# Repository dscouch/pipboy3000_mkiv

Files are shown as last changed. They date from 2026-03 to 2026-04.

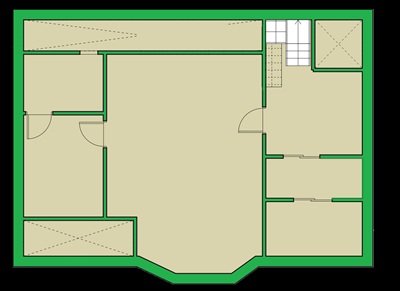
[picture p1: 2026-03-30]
images/map3.jpg

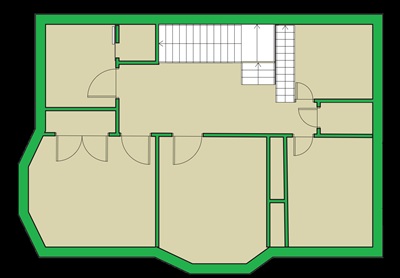
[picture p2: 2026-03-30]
images/map2.jpg

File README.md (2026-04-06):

# Vault 27 Engineering Logs: Easter 2026 Pip-Boy Project

## Overview
A multiplayer Pip-Boy 3000 (Mark IV) replica built for an immersive Easter puzzle experience. The system relies on asymmetric gameplay (similar to *Keep Talking and Nobody Explodes*), forcing two Vault Dwellers (793 and 612) to cooperate, swap roles, and manage "Radiation Sickness" to decode a final meta-puzzle.

## Hardware Architecture
* **Main Display:** 5" ESP32-S3 Capacitive Touch Display - VIEWE Model：UEDX80480050E-WB-A https://viewedisplay.com/product/esp32-5-inch-800x480-rgb-ips-tft-display-touch-screen-arduino-lvgl/
* **Co-processor:** ESP32-C3 Super Mini connected via serial. Dedicated to efficient BLE MAC address scanning for radiation hotspots, and driving a haptic motor and piezo speaker for Geiger counter feedback.
* **RFID/NFC:** PN532 module for localized object scanning. (in I2C mode)
* **Power:** USB plug to a  TP4056 lipo charger feeding into an MT3608 Boost Converter to make a 5v supply. Currently powered by a single 18650, the battery is severly undersized for any longevity. (also the power meter is pretty bad at accurately measuring the voltage.)
* **I/O Expansion:** PCF8575 or MCP23017 I/O expander for managing peripherals like rotary encoders and LEDs.(have not acquired...  on hold)
* **Radiation Sources (x4):** Xiao-ESP32-C3 microcontrollers running `esp32_ble_server`.
* **Note:** the wiring from the rotary encoder is red/black for the push button switch and blue/green/yellow for the encoder portion. (find ports for this ...  and a use!)
* **Also Note:** There is a speaker buried in the front panel that I still haven't decided what to do with. 

## UEDX80480050E Board GPIO Selection
* **UART for Co-processor** Used marked Tx/Rx next to GND on left header set.  Also used by USB/UART but available when not updating
* **PN532** GND=GND, SDA=GPIO19, SCL=GPIO20 on the left and VCC connects to the top of that header
* **5v Power** Tapped the left side of diode D3 that is on VBUS2 of the USB port which enables ability to input 5v from a battery source for regulation into 3V3 VDD

## ID's to track ##
* **Alpha UID:** 04-63-EB-5B-C2-2A-81
* **Beta UID:** 04-21-75-94-D2-2A-81
* **Charlie UID:** 04-FA-F4-94-D2-2A-81
* **Delta UID:** 04-A9-75-5B-C2-2A-81
* **1:**  UID: 04-E5-7B-5B-C2-2A-81
* **2:**  UID: 04-54-55-5B-C2-2A-81
## DWELLER PIP BOY SERIAL NUMS ##
* **Dweller 793:** E793X4
* **Dweller 612:** D612Z5

## UI Design Note ##
Due to the physical design and shape of the pip-boy the screen is more "squarish" with a portion of the 5" esp32 display actually insde the case and not visible.
This means that functionally we only have a 600x480 screen starting at x=200, y=0.  All visible UI components and LVGL widgets should be contained in that area of the screen.

## Software & Infrastructure
* **Framework:** ESPHome integrated with Home Assistant.
* **Codebase Structure:** A highly modular design utilizing YAML anchors and substitutions within a single document. This allows seamless switching of parameters between Dweller 793 and 612 without relying on multiple `!include` files.
* **State Management:** Home Assistant acts as the Overseer, handling cross-device state syncing via `input_number.dweller_${id}_xxx`, game tweaks, and manual triggers (like the Reactor Meltdown) and the mystery cell in the Memory Core Repair menu

## Gameplay Mechanics
* **Radiation Management:** Players scan for specific BLE MAC addresses at 4 hotspots. Staying in a hotspot increases Rads. If Rads exceed 25, the HUD and docs glitch out, forcing players to swap roles (Scanner vs. Manual Reader).
* **Anti-Cheese Systems:** Scans have strict 10-second timeouts. Furthermore, the scanner must actively take radiation damage (Rads > 25) to solve the puzzle, preventing players from simply disabling the radiation source.
* **Progression:** Solving the 4 hotspot puzzles yields encrypted data fragments stored in the INV Tab. The S.P.E.C.I.A.L. stats (STAT Tab) act as the decryption cipher, providing the variables needed for the final logic grid puzzle (DATA Tab).

## Menus
* **STAT** Shows RADs and basic information (can expand this) - STATUS, SPECIAL, and PERKS - SPECIAL contains stats that will change when enough HP is gained and will show the pad to unlock the final encyrpted message.
* **INV** Will be the collection point for the puzzle data and the scanner for the 4 radiation clues (KTANE style)
* **DATA** magic grid where the cells have to add to 30 in every row and colunn and cells values can't be duplicated. Some of the cells are locked and one special cell in the upper left side is actually controlled by the other pip boy.  There is a mystery cell outside the grid that is what controls the upper left cell on the other pip boy.
* **MAP** contains a map (just a static image) of the house with pulsating dots (4) indicating where the radiation source puzzles are located.  In a submenu it also contains the docs for solving the puzzles.  The docs can't be opened (or glitch) when rads>25 to prevent both dwellers from being at the source at the same time.

## Current Development Roadmap

* **Game Logic:** Developing the core logic for the INV, MAP, and RADIO tabs.
* **DATA MENU** finish configuring the puzzle and connect the mystery cell through HomeAssistant
* **MAP MENU** Load screen with mini map of house. figure out how to overlay the beacon locations (figure out locations)(done) - Create menu and doc system where the docs are stored in HA and loaded on the fly as needed (or we can just store it in code if we have enough space)
* **INV MENU** Still thinking about this one. I kind of want to have 4 items displayed and when you NFC scan a beacon it opens one of the puzzles. Maybe the puzzles are on a completely different page and we just use the INV to record which ones they got and provide the encrypted messages?  Anyway, the puzzles need to be of a specific KTANE type but have 4 defined puzzles (images or text) that can be rotated through.  there's an active countdown timer and the beacon has to be rescanned every 10 seconds to reset the countdown and continue or the puzzle blanks out and if you rescan after the countdown runs out you get the next puzzle.
* **DEATH**  In the potential event that one of them "DIES" it will flip to a screen that says something like "Vault Dweller sustained too much damage to continue.  INITIATING CLONING SEQUENCE (with a timeout timer of 99 seconds) at which point the pip-boy reboots.  Attempting to reboot the pip-boy before cloning is complete will just drop them in the same page with a fresh 99 second timer - completion managed by HomeAssistant.  All stats and accomplishments should be saved in HomeAssistant and won't be lost due to death or pip-boy reboots or failures.  (overseer has game reset control for testing and situational restarts)
* **Vaultboy Animation** figure out how to animate him (done)
* **Boot Screen:** Implementing a realistic Mark IV console-style scrolling text sequence featuring RobCo copyright, the `${pip_version}`, and biometrics initialization. (done)
* * **RAD meter** reconnect to co-processor for display (done)
 
* Final mapping
***

## Final Puzzle Role & Docs Mapping

| Puzzle (Player‑Facing Name) | Internal Puzzle Type | Defuser (Interacts with Puzzle) | Docs Holder (Reads Manual) |
| --- | --- | --- | --- |
| **Manual Override** | Button puzzle (KTANE‑inspired) | **Dweller 612** | **Dweller 793** |
| **Port Manifold** *(Alpha)* | Switch / Port puzzle | **Dweller 612** | **Dweller 793** |
| **Signal Bus** | Wires puzzle | **Dweller 793** | **Dweller 612** |
| **Authorization Lattice** | Keypad / Grid puzzle | **Dweller 793** | **Dweller 612** |

***
Manual Override – Final Rules
Seed 0

Button text: ABORT
If exactly one indicator (CAR or FRK) is lit → PRESS
Otherwise → HOLD
Strip: Blue → release when timer shows 8

Seed 1

Button color: Red
If CAR is lit → PRESS
Otherwise → HOLD

Seed 2

Button color: Blue
PRESS only when timer shows 3
Any other press or any hold → failure

Seed 3

Button color: Black
Indicators: none
Always HOLD
Strip: White → release when timer shows 7

## Key rules this table encodes (for future you)

*   **612 is the defuser** for puzzles that rely on **serial number logic**  
    → Manuals must live on **793**
*   **793 is the defuser** for logic / pattern puzzles  
    → Manuals must live on **612**
*   Each Pip‑Boy always has **exactly two manuals**
*   No Pip‑Boy ever has the manual for the puzzle it is currently defusing
*   Player‑facing names never reveal the mechanic

This table is now the **source of truth** for:

*   MAP button labeling
*   DOC routing
*   Future puzzle expansion

## LLM Instructions 
* Use most current esphome and lvgl commands and language.  Using .obj explicitly in lambda functions will cause compiler errors now.  (you can literally just drop the extension)

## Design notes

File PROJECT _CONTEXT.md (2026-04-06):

- Platform: ESPHome + LVGL (ESP32-S3)
- Project: Pip-Boy prop with radiation-based gameplay
- Core mechanic: radiation exposure state machine (3-up / 3-down)
- Single source of truth: `id(is_exposed)`
- Docs glitch on exposure, restore on exit
- Puzzles require continuous exposure
- HP drains during exposure, recovers otherwise
- Strict searchable comment standard: >>> [SYS-XXXX]

612 (odd indices):

0x01 0x6B 0x69
0x03 0x68 0x65
0x05 0x61 0x62
0x07 0x65 0x74

793 (even indices):

0x02 0x74 0x63
0x04 0x6E 0x63
0x06 0x69 0x6E
0x08 0x75 0x70

Button A: SLOT = 2
Button B: SLOT = 0
Button C: SLOT = 3
Button D: SLOT = 1

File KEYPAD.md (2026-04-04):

Character Set:
"$(*+./01245678?ABCDEGHIKLOPQRSTVYZacdefiklnoprvwyz

Variant 1:
  Keypad: [K,C,v,S]
  2-column symbols: [v,S,C,K]

Variant 2:
  Keypad: [$,+,Y,H]
  3-column symbols: [Y]
  2-column symbols: [$,+,H]

Variant 3:
  Keypad: [Q,a,i,w]
  2-column symbols: [a,i,w,Q]

Variant 4:
  Keypad: [e,B,R,.]
  3-column symbols: [R]
  2-column symbols: [e,.B]

Variant 5:
  Keypad: [Z,c,?,1]
  2-column symbols: [Z,1,?,c]

Used symbols:  K,C,v,S,$,+,R,H,Q,a,i,w,e,B,.,Z,c,?,1,Y
A 6 columns of 7 characters each = 42 characters in the doc

a B v S Q e
K $ Q e Z Y
$ C R . + Z
v Y a Y c K
. + H B i 1
C w i c ? ?
S H w R 1 R

This is just for coding validation later (players derive it from the manual):

* Variant 1 (K,C,v,S) → Column 1 → order: K → v → C → S
* Variant 2 ($,+,Y,H) → Column 2 → order: $ → Y → + → H
* Variant 3 (Q,a,i,w) → Column 3 → order: Q → a → i → w
* Variant 4 (e,B,R,.) → Column 4 → order: e → . → B → R
* Variant 5 (Z,c,?,1) → Column 5 → order: Z → c → ? → 1

Implement the Delta keypad UI logic:

4 buttons with glyph font
Track press order
Lock buttons once pressed
On 4 presses:

validate order
flip indicator (red → green)
exit puzzle

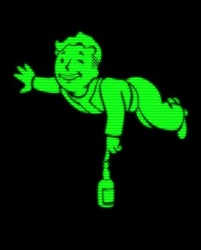
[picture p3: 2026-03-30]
images/agility.jpg

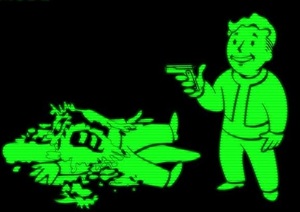
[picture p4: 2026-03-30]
images/perks.jpg

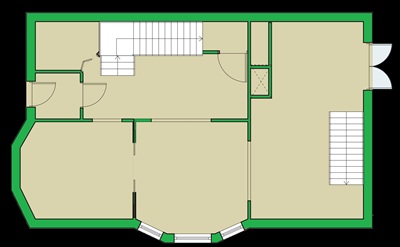
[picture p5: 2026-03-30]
images/map1.jpg

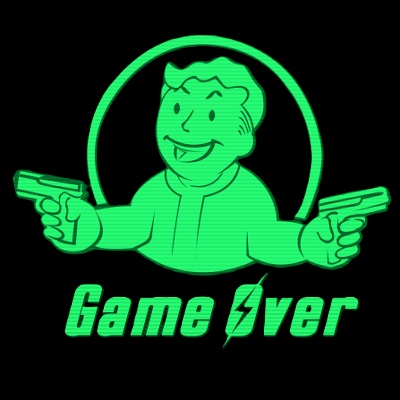
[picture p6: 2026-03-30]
images/gameover.jpg

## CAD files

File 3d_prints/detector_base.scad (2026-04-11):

include <module.scad>
ring_height = 2.8;
ring_radius = 10;
ring_width = 2;
rotation_angle = 20;
facets = 72;
translate([0,0,-10]){
difference() {
    // Create full ring using tube module
    tube(
        outer_radius = ring_radius,
        inner_radius = ring_radius - ring_width,
        height = ring_height,
        center = true
    );
    
    // Cut away negative y half
    translate([0, -ring_radius, 0])
    cube([2*ring_radius, 2*ring_radius, ring_height + 1], center = true);
}}
rotate([0, 0, -rotation_angle])
translate([0,0,-10])
/*
difference() {
    tube(
        outer_radius = ring_radius,
        inner_radius = ring_radius - ring_width,
        height = ring_height,
        center = true
    );
    
    translate([0, -ring_radius, 0])
    cube([2*ring_radius, 2*ring_radius, ring_height + 1], center = true);
}
difference() {
    cylinder(
        h = ring_height,
        r = ring_radius,
        center = true,
        $fn = facets
    );
    
    // Cut away positive y half
    translate([0, ring_radius, 0])
    cube([2*ring_radius, 2*ring_radius, ring_height + 1], center = true);
} */

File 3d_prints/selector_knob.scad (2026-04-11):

include <module.scad>
height = 15;
radius = 15;
rounding_radius = 2;
facets = 64;
inner_height = 10.01;  // Extended to create through-bottom opening
inner_radius = 13;
second_hollow_height = 3;
second_hollow_radius = 11;
h_cut = 3;
r_cut = 2;
x_offset = 11;
z_base = 10;
n_cutouts = 16;
difference() {
    // Outer rounded cylinder
    translate([0,0,height/2])
    rounded_cylinder(
        height = height,
        radius = radius,
        rounding_radius = rounding_radius,
        facets = facets
    );
    
    // Inner hollow cylinder - aligned with bottom plane
    translate([0, 0, 0])
    cylinder(
        h = inner_height,
        r = inner_radius,
        center = false,
        $fn = facets
    );
    
    // Second hollow cylinder stacked on top of the first
    translate([0, 0, inner_height])
    cylinder(
        h = second_hollow_height,
        r = second_hollow_radius,
        center = false,
        $fn = facets
    );
    
    // 16 cylindrical cutouts in circular pattern
    for (i = [0:n_cutouts-1]) {
        rotate([0, 0, i * (360/n_cutouts)])
        translate([x_offset, 0, z_base])
        cylinder(
            h = h_cut,
            r = r_cut,
            center = false,
            $fn = facets
        );
    }
}

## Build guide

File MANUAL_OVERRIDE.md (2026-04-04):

Seed 0

Button text: ABORT
If exactly one indicator (CAR or FRK) is lit → PRESS
Otherwise → HOLD
Strip: Blue → release when timer shows 8

Seed 1

Button color: Red
If CAR is lit → PRESS
Otherwise → HOLD

Seed 2

Button color: Blue
PRESS only when timer shows 3
Any other press or any hold → failure

Seed 3

Button color: Black
Indicators: none
Always HOLD
Strip: White → release when timer shows 7

If the button says "ABORT" and exactly one indicator is lit, PRESS, otherwise HOLD
if the button colour is Red and CAR is lit, PRESS, otherwise HOLD
if the button colour is blue PRESS only when the timer shows "3"
if the Button colour is Black always HOLD
If the Button colour is GREEN and one indicator is lit HOLD (fake)
if the both indicators are lit and the button is white, PRESS immediately
If the button says "detonate" and is yellow HOLD

      MANUAL OVERRIDE
      Operational Instructions

      Follow these rules in the order they are listed.
      Perform the first action that applies.

      If instructed to HOLD the button, refer to
      "Releasing a Held Button."

      PRESS OR HOLD RULES

      1. If both indicators are lit and the button is WHITE:
         PRESS immediately.

      2. If the button color is BLUE:
         PRESS only when the countdown timer shows 3.

      3. If the button says "ABORT" and exactly one indicator is lit:
         PRESS.
         Otherwise HOLD.

      4. If the button color is BLACK:
         HOLD.

      5. If the button says "DETONATE" and the button is BLUE:
         PRESS.

      6. If the button color is RED and CAR is lit:
         PRESS.
         Otherwise HOLD.

      7. If the button color is GREEN and exactly one indicator is lit:
         HOLD.

      RELEASING A HELD BUTTON

      If you are instructed to HOLD the button, observe the strip color
      and release the button only when the countdown timer shows the
      correct value.

      Black strip: release when the timer shows 3
      White strip: release when the timer shows 7
      Yellow strip: release when the timer shows 6
      Any other color strip: release when the timer shows 8

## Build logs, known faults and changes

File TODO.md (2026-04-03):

# ✅ FINAL ADJUSTED TODO LIST

## A. Core Mechanics (must be solid first)

1.  **Lock the puzzle lifecycle model**
    *   Puzzle opens only if:
        *   Correct NFC tag
        *   `is_exposed == true` OR cheat mode
    *   Puzzle remains open only if:
        *   NFC rescan occurs within 10 seconds
        *   Radiation exposure is maintained
    *   On close (timeout or rad loss):
        *   Overlay closes
        *   New random puzzle variant is selected next time

2.  **Prevent repeat puzzle variants**
    *   Track `last_puzzle_seed[puzzle_id]`
    *   On new open:
        *   Re‑roll until `new_seed != last_seed`
    *   This is important to force new shouting to the expert

3.  **Standardize “puzzle solved” handling**
    *   If already solved and scanned again:
        *   Do **not** reopen puzzle
        *   Show a popup message:
            *   “CACHE ALREADY DECRYPTED”
        *   Auto‑close after short delay

***

## B. Radiation Puzzles (Alpha / Beta / Charlie / Delta)

### Shared behavior (do once, reused)

4.  **Decouple solve time from exposure leash**
    *   Remove any assumption puzzles must be solvable in 10 seconds
    *   Timer only governs **rescan requirement**
    *   HP drain continues independently

5.  **HP damage rate decision**
    ✅ Recommendation: **1 HP every 2 seconds**
    *   Reason:
        *   2.5 minutes to death = strong pressure
        *   Encourages speed and communication
        *   Still allows recovery by backing out
    *   Action:
        *   Change HP drain interval from `3s → 2s`

***

### Individual puzzle definitions

5.5 **Alpha - something something**

6.  **Beta – Button puzzle**
    *   Inputs:
        *   Button color
        *   Button label
        *   Indicator state(s)
    *   Variants:
        *   At least 4 rule sets
    *   Failure:
        *   Wrong press triggers penalty
    *   Success:
        *   Fragment revealed
        *   `inv_solved[beta] = true`

7.  **Charlie – Wires puzzle**
    *   Display:
        *   3–6 vertical wires
    *   Variants:
        *   Color sequences
        *   Rule modifiers from indicators or serial
    *   Interaction:
        *   Touch to cut
    *   Wrong cut:
        *   Immediate penalty
    *   Correct cut:
        *   Puzzle solved

8.  **Delta – Keypad puzzle**
    *   Display:
        *   4 symbols chosen from a column
    *   Variants:
        *   Multiple columns
        *   Shuffled order
    *   Interaction:
        *   Tap symbols in sequence
    *   Wrong order:
        *   Penalty, but puzzle stays open
    *   Correct order:
        *   Solve + fragment

***

## C. Inventory & Fragment Assembly

9.  **Fragment model**
    *   Each Dweller collects **4 fragments**
    *   Total fragments required: **8**
    *   Fragments are:
        *   Persistent across reboots
        *   Viewable in INV
        *   Distinct per Dweller

10. **SPECIAL stat dependency**

*   Final solution requires:
    *   All 8 fragments
    *   A combination of:
        *   Current SPECIAL stats
        *   Stats that shift with XP
*   Action:
    *   Define how XP alters SPECIAL
    *   Make this deterministic and documentable

***

## D. DATA Grid Puzzle (reworked)

11. **Abandon buttonmatrix**

*   Replace with:
    *   16 individual buttons in a grid layout
*   Benefits:
    *   Easy background color changes
    *   Easy lock visuals
    *   Easy duplicate detection

12. **Implement row + column parity rules**

*   Each row sum == target
*   Each column sum == target
*   No duplicate values allowed

13. **Visual feedback**

*   Cell background changes if:
    *   Duplicate detected
    *   Row/column invalid
*   Locked cells clearly styled

14. **Freeze grid on success**

*   Disable all buttons
*   Change grid color scheme
*   Trigger “final assembly unlocked”

***

## E. Meltdown Sequence (stabilization puzzle)

15. **Replace static meltdown timer**

*   Use a **temperature variable**
*   Base behavior:
    *   Temp increases +5 every 3 seconds
    *   If it exceeds a threshold → failure

16. **Player interaction**

*   Players must:
    *   Adjust values (grid / controls / sliders)
    *   Counteract the temperature rise
*   Wrong adjustments:
    *   Accelerate temp increase
*   Correct adjustments:
    *   Slow or reverse increase

17. **Success / failure**

*   Success:
    *   Temperature stabilized for N seconds
    *   Meltdown aborted
*   Failure:
    *   Forced death or system reset

***

## F. Feedback & Clarity (important, not cosmetic)

18. **Rescan feedback**

*   On successful rescan:
    *   Brief visual or text confirmation
*   On missed rescan:
    *   Explicit “SIGNAL LOST” feedback

19. **Solved puzzle scan feedback**

*   Popup message
*   No puzzle overlay
*   No HP change

***

## G. Stretch goals

*   Sliding scale for HP loss by radiation
*   Rotary encoder
*   External speaker logic
*   Additional sensors
*   More animation polish
*   Turn off Sound and Haptic from HA
*   calibrate battery meters better for each device (it seems incorrect but not critically so)

***

## Bottom‑line design validation

*   Pressure should come from **HP loss**, not timers
*   Re‑randomizing puzzles is a feature, not a problem
*   DATA grid as individual buttons is the right call
*   Meltdown as **active stabilization** is much more fun

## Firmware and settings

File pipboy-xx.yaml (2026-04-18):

# =========================================
# DWELLER IDENTITY & SECRETS
# =========================================
substitutions:

  dweller_id: "527"    # 793 or 612  now with 527
  other_id: "793"
  device_name: "pipboy-${dweller_id}"
  friendly_name: "Vault Dweller ${dweller_id}"
  batt_adc_offset: "-0.068" #612:-0.068 793:???
  scr_align: "TOP_RIGHT"   #if pipboy on left arm: TOP_LEFT, if on right arm: TOP_RIGHT
  
  # Hex Puzzle Arrays
  data_793_grid: &grid793 '{0x0, 0xD, 0x2, 0x1, 0xC, 0x9, 0x4, 0xA, 0x7, 0x8, 0x6, 0x5, 0xB, 0x3, 0xE, 0x0}'
  data_612_grid: &grid612 '{0x0, 0x4, 0xF, 0xE, 0x5, 0x9, 0xD, 0x2, 0xA, 0x6, 0x1, 0x0, 0xB, 0xC, 0x7, 0x8}'
  cell_793_lock: &lock793 '{true, false, false, false, false, true, false, false, false, false, true, false, false, false, false, true}'
  cell_612_lock: &lock612 '{true, false, false, false, false, false, false, true, false, true, false, false, false, false, true, false}'
  
  # ACTIVE DWELLER SELECTOR
  active_grid: *grid612 
  active_lock: *lock612


  # ----------KEEP EVERYTHING ABOVE HERE SEPARATE-------------

  # DWELLER PIP BOY SERIAL NUMS
  # Dweller 793: E793X4
  # Dweller 612: D612Z5

# =============================================================================
# >>> [SYS-INDEX] PIP-BOY SYSTEM INDEX (SEARCH ANCHORS)
#
# >>> [SYS-BOOT] Boot sequence, version banner, initial UI bring-up
# >>> [SYS-HA-CONN] Home Assistant API, encryption, and state sync
#
# >>> [SYS-RAD-UART] Coprocessor UART parsing (RAD / BATRAW)
# >>> [SYS-RAD-SM] Radiation exposure state machine (3-up / 3-down with deadband)
#
# >>> [SYS-DOC-TEXT] Canonical DOC text storage (globals)
# >>> [SYS-DOC-INIT] Initial DOC injection into LVGL widgets
# >>> [SYS-DOC-STATE] Exposure-driven DOC state changes (enter / exit)
# >>> [SYS-DOC-GLITCH] DOC corruption animation during exposure
# >>> [SYS-DOC-RESTORE] DOC restoration after exposure ends
#
# >>> [SYS-UI-STAT] STAT tab: status, SPECIAL, perks, toggles
# >>> [SYS-UI-INV] INV tab: inventory buttons, overlays, puzzle launch
# >>> [SYS-UI-DATA] DATA tab: memory core puzzle and linked cell logic
# >>> [SYS-UI-MAP] MAP tab: page navigation and exposure-gated docs access
#
# >>> [SYS-GAME-HP] HP drain, recovery, death triggers, persistence
# >>> [SYS-GAME-XP] XP tracking and HA override publishing
#
# >>> [SYS-GAME-PUZ] Global puzzle lifecycle (gating, timers, variants, exits)
# >>> [SYS-PUZ-ALPHA] Puzzle Alpha – hardware switch / port logic (shared HA state)
# >>> [SYS-PUZ-BETA] Puzzle Beta – button-based radiation puzzle
# >>> [SYS-PUZ-CHARLIE] Puzzle Charlie – wire-cutting radiation puzzle
# >>> [SYS-PUZ-DELTA] Puzzle Delta – keypad / symbol sequence puzzle
#
# >>> [SYS-DEATH] Cloning / death lifecycle and reboot flow
# >>> [SYS-DIAG] Heap, fragmentation, telemetry, runtime diagnostics
# >>> [SYS-CAL] Calibration and tuning values (thresholds, offsets, fudge)
# =============================================================================


  pip_version: "v2.8.8"

# =========================================
# ESPHOME 
# =========================================

esphome:
  name: ${device_name}
  friendly_name: ${friendly_name}
  min_version: 2026.2.4
  name_add_mac_suffix: false
  on_boot:
    priority: 800
    then:
      - output.turn_on: backlight_pin
      - script.execute: robco_boot_sequence
      - lambda: |-
          id(boot_start_time) = millis(); 
          ESP_LOGI("ROBCO", "=============================================");
          ESP_LOGI("ROBCO", " PIP-OS(R) V7.1.0.8 - COPYRIGHT ROBCO IND.");
          ESP_LOGI("ROBCO", " COMPILED FIRMWARE VERSION: %s", "${pip_version}");
          ESP_LOGI("ROBCO", "=============================================");

esp32:
  board: esp32-s3-devkitc-1
  variant: esp32s3
  flash_size: 16MB
  cpu_frequency: 160MHz  # because battery powered. Otherwise default = 240MHZ
  framework:
    type: esp-idf
    sdkconfig_options:
      CONFIG_ESP32S3_DEFAULT_CPU_FREQ_160: y
      CONFIG_ESP32S3_DATA_CACHE_64KB: y
      CONFIG_SPIRAM_FETCH_INSTRUCTIONS: y
      CONFIG_SPIRAM_RODATA: y
      CONFIG_ESP_MAIN_TASK_STACK_SIZE: "65536"

psram:
  mode: octal
  speed: 80MHz

logger:
  level: DEBUG
  hardware_uart: USB_SERIAL_JTAG
# =========================================
# HOME ASSISTANT CONNECTION
# =========================================
# (Ensure your secrets.yaml has these defined!)
api:
  reboot_timeout: 0s
  encryption:
    key: !secret pipboy_api_key 

wifi:
  ssid: !secret wifi_ssid
  password: !secret wifi_password
  domain: .home 
  reboot_timeout: 0s

ota:
  - platform: esphome

debug: 
  update_interval: 5s
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

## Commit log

2026-03-17 Add configuration for Vault 27 Dweller's Pip-Boy
    This YAML file defines the configuration for a Vault 27 Dweller's Pip-Boy, including versioning, device settings, system configuration, and UI rendering.
2026-03-17 Add initial configuration for ESP32 BLE server
2026-03-17 Add pip-boy coprocessor configuration
    This YAML configuration sets up the pip-boy coprocessor for BLE scanning, haptic feedback, and sound simulation. It includes sensor definitions, output controls, and scripts for handling radiation de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
2026-03-17 Fix indentation for on_boot configuration
    [pipboy-xx.yaml]
2026-03-17 Refine elapsed time checks for Pip-Boy messages
    fixed overwriting issue on boot up
    [pipboy-xx.yaml]
2026-03-20 Create lvgl.yaml with UI configuration
    Added a new LVGL configuration file with multiple pages and widgets including tabview, roller, arc, labels, textarea, bar, buttonmatrix, switch, and spinbox.
2026-03-21 Fix formatting issues in pipboy-xx.yaml
    [pipboy-xx.yaml]
2026-03-21 Update pip version and improve UART and UI settings
    Updated pip version and modified UART configuration. Enhanced boot sequence and UI initialization with new styles and button configurations.
2026-03-21 Add control properties to buttons in pipboy-xx.yaml
2026-03-22 Update README with wiring notes and speaker info
    Added wiring notes for rotary encoder and speaker status.
2026-03-23 Enable Vault Boy animation and adjust UI layout
    and added labels for sound and vibrate settings
    [pipboy-xx.yaml]
2026-03-25 Update pipboy-xx.yaml
    tweaked some configs and tried to fix the tab configuration
    [pipboy-xx.yaml]
2026-03-26 Update pipboy-xx.yaml
    adding in the inventory tab
    fixed the blue tab underline
    added additional images
    [pipboy-xx.yaml]
2026-03-26 Update pipboy-xx.yaml
    fixed settings and took out some warnings
    [pipboy-xx.yaml]
2026-03-28 Update pipboy-xx.yaml
    added functionality to take damage and repair damage (HP)
    track XP and HP, diagnostics, etc.
    [pipboy-xx.yaml]
2026-03-30 Document 5v power input for battery regulation
    Added information about 5v power input from battery source.
2026-03-30 Add power supply information to README
    Added power supply details to hardware architecture section.
2026-03-30 Modify BLE MAC addresses and add comments
    Updated MAC addresses for BLE beacons and added battery monitoring comments.
2026-03-30 Update version to 1.2 and add battery monitoring
    Added battery voltage measurement to monitor battery status.
2026-03-31 Update pip_version and add battery data handling
    Updated pip_version to v2.5.3 and added battery data handling.
2026-03-31 Refactor battery handling and UI elements
2026-03-31 Swap dweller IDs and update pip version
    [pipboy-xx.yaml]
2026-04-02 Update pip-boy-coproc.yaml for version 1.3
    Updated version to 1.3, modified battery monitoring settings, and added debug UART functionality.
2026-04-02 Update pipboy-xx.yaml
    fixed issues with doc corruption (not working correctly)
    now they corrupt really well! :D
    [pipboy-xx.yaml]
2026-04-02 Add project context for Pip-Boy prop development
2026-04-02 refactored code for better switching between puzzles
    stubbed out spots for beta, charlie, and delta puzzles.
2026-04-03 Add calibration note for battery meters
2026-04-03 Update pip version and modify HP conditions
    FIXED DATA PUZZLE!!!
    Also working on the Alpha/Delta puzzle layout.
    [pipboy-xx.yaml]
2026-04-03 finalized DATA puzzle and fixed win conditions
    [pipboy-xx.yaml]
2026-04-03 Update README with manual override final rules
    Added final rules for manual override with specific seeds and button conditions.
2026-04-06 Update power section with battery and measurement notes
    Added note about battery size and power meter accuracy.
2026-04-11 Add selector knob SCAD model with cutouts
    Created a selector knob model with inner hollow and cutouts.
    [selector_knob.scad]
2026-04-11 Delete code.scad
    moved to 3d_prints
    [code.scad]
2026-04-18 Refactor UI layout and dimensions in pipboy-xx.yaml
    Adjusted layout and dimensions for UI elements, including battery meter and navigation menu.
